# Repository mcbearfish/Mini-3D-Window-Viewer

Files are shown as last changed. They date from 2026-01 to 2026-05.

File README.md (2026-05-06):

# 3D Window Project

## About
This is a developmental project intended to refresh my skills on designing and programming an STM32 microcontroller board. I chose a project scope that I believed would provide difficult circuit and programming challenges. I will document the development process in this README.<br />

If you stumble across this project feel free to use it for educational purposes. If you find errors or have questions about the circuit design or code feel free to reach out. Please cite this repository as a source if you plan to use it.<br />

## Table of Contents
- [Project Description](#project-description)
- [Demo Video](#demo-video)
- [Hardware / Software Used](#hardware--software-used)
- [Circuit Design](#circuit-design)
- [Box Design](#box-design)
- [Code Design](#code-design)
- [Notes on AI Assistance](#notes-on-ai-assistance)
- [Final Result](#final-result)

## Project Description
This project is the 3D Window Viewer.<br />

When placed on a flat surface, the device on startup will create a window into a 3D scene of a hammer (Boiler Up and Hail Purdue!). After startup, tilting and rotating the device updates the view of a 3D hammer while the virtual position remains anchored.<br />

This project uses I2C accelerometer, gyroscope, and magnetometer sensors to estimate device orientation in C. The original goal was IMU-only position tracking, but drift made that impractical, so I redesigned the demo around constrained motion. <br />

I designed my own custom STM32 development board and sensor board using KiCad Schematic and PCB Design Software. <br />

## Demo Video
Everything Is AWESOME (https://www.youtube.com/watch?v=Y7tffPQoLfw "Everything Is AWESOME")

## Hardware / Software Used
- STM32 microcontroller
- Custom STM32 main PCB
- Custom sensor PCB
- Accelerometer, gyroscope, and magnetometer over I2C
- LCD display
- KiCad for schematic and PCB design
- CLion IDE
- C firmware

## Circuit Design
#### STM32 Circuit
<br />
This STM32 chip was chosen for its large number of GPIO pins and processing capabilities.

#### Button
<br />
Simple button circuit to test user inputs.

#### LEDs
<br />
Used for initial testing and debugging.

#### Crystal Oscillator
<br />
Provides a highly stable, accurate, and precise frequency reference.

#### USB-C Connector
<br />
Provides power to the board.

#### Boot Switch
<br />
Reset switch.

#### Mounting Holes
<br />
Grounded pads to use for mounting and probe testing.

#### Pin Connectors
<br />

#### Buck Converter
<br />
Chosen to smooth 5V to 3.3V for STM32 chip and sensors.

#### Accelerometer and Gyroscope
<br />
Chosen to estimate device orientation and motion. IMU-only position tracking was tested, but drift made it impractical for this version.

#### Magnetometer
<br />
Chosen to improve heading estimation and help correct gyro drift over time.

#### Pin Connector
<br />

#### Mounting Holes
<br />

#### Notes
I found Google's Gemini AI tool to be extremely helpful during this design process. Especially with mapping the pinout of the display to STM32. I used a cheap knockoff with no documentation and poor pinout labels. In the future may need to remap pins if display fails to work. See ARSensors project for second Board meant to connect sensors to this main board.<br />

Manufacturing files can be found for each board in this repository.<br />

#### Main PCB
<br />

<br />

<br />

<br />

#### Sensors PCB
<br />

<br />

<br />

<br />

#### Design Process
Designing my first board in almost 4 years was a great experience. In the workspace I have been living in a more software heavy environment. I found this project to be a great refresher of my skills.<br />

I found the initial research phase to be quite enjoyable and straightforward. I easily identified the types of sensors, display, and STM32 chip I thought would be capable for the performance I wanted. Now that I identified the key components it was time to begin creating the schematic.<br />

I quickly realized this was a larger challenge than my senior design project. Although I took a significant part in the circuit design, I realized how beneficial it was having a team of 4 people in multiple disciplines. The components I selected for this project were much more sophisticated than what was chosen for the senior design project. I was honestly a little overwhelmed at the start. I had to take my time and started to break components down. I started with the most important part, the STM32 chip. <br />

For the STM32 I first connected any power related pins and decoupling capacitors. Then I used the STM32CubeMX tool to assign pinouts. I knew between the display and other peripherals I needed a lot of pins, so I started by making sure the chip was capable of supporting them all. Once I verified the chip was capable I began connecting components. The most critical was the USB-C connector, which flashes code onto the chip. The USB-C will also provide power to the whole system. I spent quite a bit of time researching possible power designs. The USB-C provides 5V and I need 3.3V for the STM32 and sensors. I eventually decided on a synchronous buck converter because it would provide an efficient and stable step down from 5V to 3.3V. The display needs 5V, so I decided on a simple low-pass filter because it would provide a clean signal and I have experience with designing those on circuit boards in the past.<br />

Next I added the sensors. I found the datasheets to be extremely helpful. The design process was made much easier by following the typical application circuits that they detailed. Then I added the display, button, and some LEDs. The extra LEDs and button will be useful at the start of programming to make sure the board can properly run code and debug. Lastly I added a connector for debug pins.<br />

Now that I had a schematic to follow I moved onto the PCB layout. This portion was much more difficult than expected. It was at this point I had to take into account physical and cost restrictions. JLCPCB was my choice of board manufacturer. To minimize costs I decided on a 2 layer board, which gave me a lot of physical trace constraints.  Also, since the sensors are a bit costly, I decided to move them to a second circuit board to save on future costs. With these new challenges I had to go back to my schematic and STM32CubeMX. Unfortunately I was not able to place my STM32 pinouts more conveniently to minimize trace crossovers. At this point I decided to go with a more generic pin layout that I can wire with some 2.54mm connectors to minimize my trace lengths and crossovers. In the future I will look at more layered boards or other STM32 chips as potential solutions.<br />

To minimize costs on JLCPCB I tried to identify basic parts in the JLCPCB library. Not all parts selected were in that and drove up the cost (~$3 per part not in the basic library). In the future I will place more emphasis on this to lower my costs.<br />

Major credit to Phil's Lab PCB Design video: https://www.youtube.com/watch?v=aVUqaB0IMh4. This was a great refresher on circuit board design and I highly recommend his channel.<br />

#### Soldering and Assembly
When ordering the board I decided that to save on costs to I would hand solder some of the components. This involved things the STM32 chip, USB-C connector, asynchronous buck converter, buttons, and pins. I felt this was a great skill refresher. I took it slow and steady. I started with easier items like the pins and buttons to get back into the flow of things. The picture below is from right before I went to solder the STM chip.<br />
<br />

I bought a cheap soldering station and found it pretty useful when adding the smaller components. In the picture below you can see a cheaper soldering iron. I found this ok for the larger components but, I decided it was safer to spend the money and get a proper iron for the delicate items like the USB-C and STM32 chip.<br />
<br />

### Box Design
I bought a simple project box and placed the main board inside the box. I left the sensor board on top along with the display to keep them on the same level.


## Code Design
#### Initial Project Scope
The initial goal of the project was to use the IMU sensors to track the 3D coordinates of the device so that it could act as a camera. The camera would then be able to view a 3D object fixed in space from all angles and get closer or farther away.<br />

#### Limitations of IMU Sensors
While prototyping I found that it was not feasible to use the IMU sensors alone for positional tracking. The significant position drift was too much to overcome, even with adjusting bias in the Kalman filter parameters. I also tested the individual sensors to check for noise and bias. Surprisingly, these cheaper sensors performed quite well. The accelerometer did display the most noise. I believe this was due to environmental sensitivities. Testing was performed on my desk and away from any electronics, this however does not guarantee a perfectly still environment. <br />

Since position is calculated by integrating acceleration twice, even with tiny errors, the positional data errors grew massive. The estimated position drifted so quickly that the 3D object would only remain visible for a split second. I determined this was unusable and decided to change scope. <br />

#### Redesign
I decided to pivot the project and try to get the most out of the current setup. I decided to simulate the camera view of the 3D object where moving and tilting the box changes camera view direction realistically, but position is anchored. <br />

#### Code Flow
The main program initializes the board, sensors, sensor fusion, and 3D engine before entering the main loop. In the loop, new sensor data is read and passed into the sensor fusion algorithm. This project uses an Extended Kalman Filter, which fuses gyroscope, accelerometer, and magnetometer data into a stable orientation estimate. That orientation estimate is then used to update the rendered 3D object and draw the pose overlay.<br />
```
main()
|
+-- HAL_Init()
+-- SystemClock_Config()
+-- MX_GPIO_Init()
+-- MX_FMC_Init()
+-- I2C_Bus_Reset()
+-- MX_I2C1_Init()
|
+-- Engine3D_Init()
|   \-- GPU_Init()
|
+-- Sensors_Init()
+-- Sensors_ShowStartupCountdown()
+-- Sensors_Calibrate()
+-- Sensors_ShowInstructionScreen()
+-- Sensors_GetReferenceFrame()
+-- EKF_Init()
+-- EKF_SetReference()
|
\-- while (1)
    +-- Sensors_Read()
    +-- EKF_Predict()
    +-- EKF_Update()
    +-- ComputeSpinCommands()
    +-- IntegrateQuat()
    +-- IsStableForReset()
    |   \-- maybe ResetObjectOrientation()
    +-- QuaternionToEulerDegrees()
    +-- Engine3D_SetCameraPose()
    +-- Engine3D_SetObjectRotation()
    +-- Engine3D_PrepareFrame()
    +-- GPU_Render(Engine3D_DrawScene)
    \-- DrawPoseOverlay()
```

## Notes on AI Assistance
Portions of the firmware were developed with assistance from AI tools, including OpenAI Codex and Google's Gemini. I used these tools to help generate code structure, debug embedded issues and tune parts of the sensor-fusion pipeline. All AI-assisted code was reviewed, tested, and modified by me before being included in the final project. <br />

I found Codex especially useful for working through embedded C issues and code organization. Gemini was useful during early design exploration, especially for brainstorming and pin-mapping support, but I had to review its output carefully because it sometimes suggested larger code changes than intended. <br />

## Final Result
The final device renders a wireframe 3D hammer on the LCD. After startup calibration, tilting or rotating the physical box updates the rendered view in real time. The device uses IMU sensor fusion for orientation estimation while keeping virtual position constrained to avoid IMU drift. <br />

This project was great for refreshing my bare-metal embedded skills. Making a device and writing code that brings it to life is always a joy. The next project should hopefully move faster now that I have regained familiarity with the whole process.

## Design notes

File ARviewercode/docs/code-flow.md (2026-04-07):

# Code Flow

This document summarizes the runtime flow of the AR viewer firmware and the relationship between the main application modules.

## Main Runtime Flow

```text
Power On / main()
|
+-- HAL_Init()
+-- SystemClock_Config()
+-- MX_GPIO_Init()
+-- MX_FMC_Init()
+-- I2C_Bus_Reset()
+-- MX_I2C1_Init()
|
+-- Engine3D_Init()
|   \-- GPU_Init()
|       \-- LCD init + clear screen
|
+-- Sensors_Init()
|   +-- Probe magnetometer
|   |   \-- If found: configure LIS3MDL
|   \-- Probe IMU
|       \-- If found: configure LSM6DS3TR-C
|
+-- Sensors_ShowStartupCountdown()
+-- Sensors_Calibrate()
|   +-- Draw calibration UI
|   +-- Collect still samples
|   +-- Compute gyro bias
|   +-- Compute accel bias/reference
|   \-- Capture mag reference if available
|
+-- Sensors_ShowInstructionScreen()
+-- Sensors_GetReferenceFrame()
+-- EKF_Init()
+-- EKF_SetReference()
|
\-- while (1)
    +-- Sensors_Read()
    |   +-- Read accel
    |   +-- Read gyro
    |   \-- Read mag if available
    |
    +-- Convert gyro mdps to rad/s
    +-- Compute dt from HAL_GetTick
    +-- EKF_Predict()
    +-- Convert accel mg to g
    +-- Magnetometer available?
    |   +-- Yes -> EKF_Update(accel + mag)
    |   \-- No  -> EKF_Update(accel only)
    |
    +-- Read EKF quaternion
    +-- Quaternion valid?
    |   +-- No -> EKF_Init() and continue
    |   \-- Yes
    |
    +-- Compute gravity_body
    +-- ComputeSpinCommands()
    +-- IntegrateQuat(object_q)
    +-- Compute motion magnitude
    +-- IsStableForReset()?
    |   +-- Yes
    |   |   +-- Accumulate still_time_s
    |   |   \-- If still_time_s >= 10 s -> ResetObjectOrientation()
    |   \-- No
    |       \-- Reset still_time_s to 0
    |
    +-- QuaternionToEulerDegrees()
    +-- Engine3D_SetCameraPose()
    +-- Engine3D_SetObjectRotation()
    +-- Engine3D_PrepareFrame()
    |   +-- Rotate vertices
    |   +-- Project points
    |   \-- Build visible line list
    |
    +-- GPU_Render(Engine3D_DrawScene)
    |   +-- Erase previous lines
    |   \-- Draw current lines
    |
    \-- DrawPoseOverlay()
```

## Module Relationships

```text
main.c
|
+-- sensor_helper.c
+-- kalman_filter.c
+-- engine3d.c
|   \-- gpu_driver.c
\-- gpu_driver.c (via sensor/UI drawing paths)
```

## Notes

- `main.c` owns system startup, the main loop, and the high-level application state.
- `sensor_helper.c` handles sensor detection, calibration, reference-frame capture, and live sensor reads.
- `kalman_filter.c` estimates device orientation from gyro, accelerometer, and optional magnetometer data.
- `engine3d.c` converts the current object orientation into projected wireframe line segments.
- `gpu_driver.c` wraps low-level LCD drawing primitives used by both the renderer and the startup/UI screens.

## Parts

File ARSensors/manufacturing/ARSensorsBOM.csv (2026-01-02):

Designator | Comment | Footprint | JLCPCB Part #
C1,C2,C3,C5 | 100n | Capacitor_SMD:C_0402_1005Metric | C1525
C4 | 1u | Capacitor_SMD:C_0402_1005Metric | C52923
R1,R2 | 3k3 | Resistor_SMD:R_0603_1608Metric | C22978
U2 | LIS3MDLTR | footprints1:LGA-12_2X2X1_STM | C478483
U3 | LSM6DSRTR | footprints:LGA-14L_2P5X3X0P83_STM | C784817

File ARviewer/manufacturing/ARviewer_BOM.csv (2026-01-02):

Comment | Designator | Footprint | JLCPCB Part #
10u | C1,C19 | Capacitor_SMD:C_0603_1608Metric | C19702
100n | C2,C3,C4,C5,C6,C8,C10,C11,C15,C17,C20,C22,C23 | Capacitor_SMD:C_0402_1005Metric | C1525
2u2 | C7,C9 | Capacitor_SMD:C_0402_1005Metric | C12530
10n | C12 | Capacitor_SMD:C_0402_1005Metric | C15195
1u | C13,C14 | Capacitor_SMD:C_0402_1005Metric | C52923
14pF | C16,C18 | Capacitor_SMD:C_0402_1005Metric | C458857
10p | C21 | Capacitor_SMD:C_0402_1005Metric | C32949
22u | C24,C25 | Capacitor_SMD:C_0805_2012Metric | C45783
GREEN | D1,D6 | LED_SMD:LED_0603_1608Metric | C2286
ORANGE | D2 | LED_SMD:LED_0603_1608Metric | C2286
BLUE | D3 | LED_SMD:LED_0603_1608Metric | C2286
YELLOW | D4 | LED_SMD:LED_0603_1608Metric | C2286
RED | D5 | LED_SMD:LED_0603_1608Metric | C2286
120R | FB1,FB2 | Inductor_SMD:L_0603_1608Metric | C14709
USB_C_Receptacle_USB2.0_16P | J2 | Connector_USB:USB_C_Receptacle_GCT_USB4105-xx-A_16P_TopMnt_Horizontal | C3020560
3.3u | L1 | Inductor_SMD:L_6.3x6.3_H3 | C206311
100k | R1 | Resistor_SMD:R_0805_2012Metric | C149504
1k | R2 | Resistor_SMD:R_0603_1608Metric | C21190
450 | R3 | Resistor_SMD:R_0402_1005Metric | C159027
1k5 | R4,R5,R6,R8,R9,R15 | Resistor_SMD:R_0603_1608Metric | C22843
10k | R7 | Resistor_SMD:R_0402_1005Metric | C25744
22 | R10 | Resistor_SMD:R_0603_1608Metric | C23345
5k1 | R11,R12 | Resistor_SMD:R_0603_1608Metric | C23186
33k2 | R13 | Resistor_SMD:R_0805_2012Metric | C37252
10k | R14 | Resistor_SMD:R_0805_2012Metric | C17414
SW_Push | SW1 | Button_Switch_THT:SW_PUSH_6mm | C557623
SW_SPDT | SW2 | Button_Switch_SMD:SW_SPDT_PCM12 | C221841
STM32F429VIT6 | U1 | Package_QFP:LQFP-100_14x14mm_P0.5mm | C92002
AP62300TWU-7 | U2 | Package_TO_SOT_SMD:TSOT-23-6 | C1883519
USBLC6-2SC6 | U3 | Package_TO_SOT_SMD:SOT-23-6 | C7519
25MHz | Y1 | Crystal:Crystal_SMD_3225-4Pin_3.2x2.5mm | C9006

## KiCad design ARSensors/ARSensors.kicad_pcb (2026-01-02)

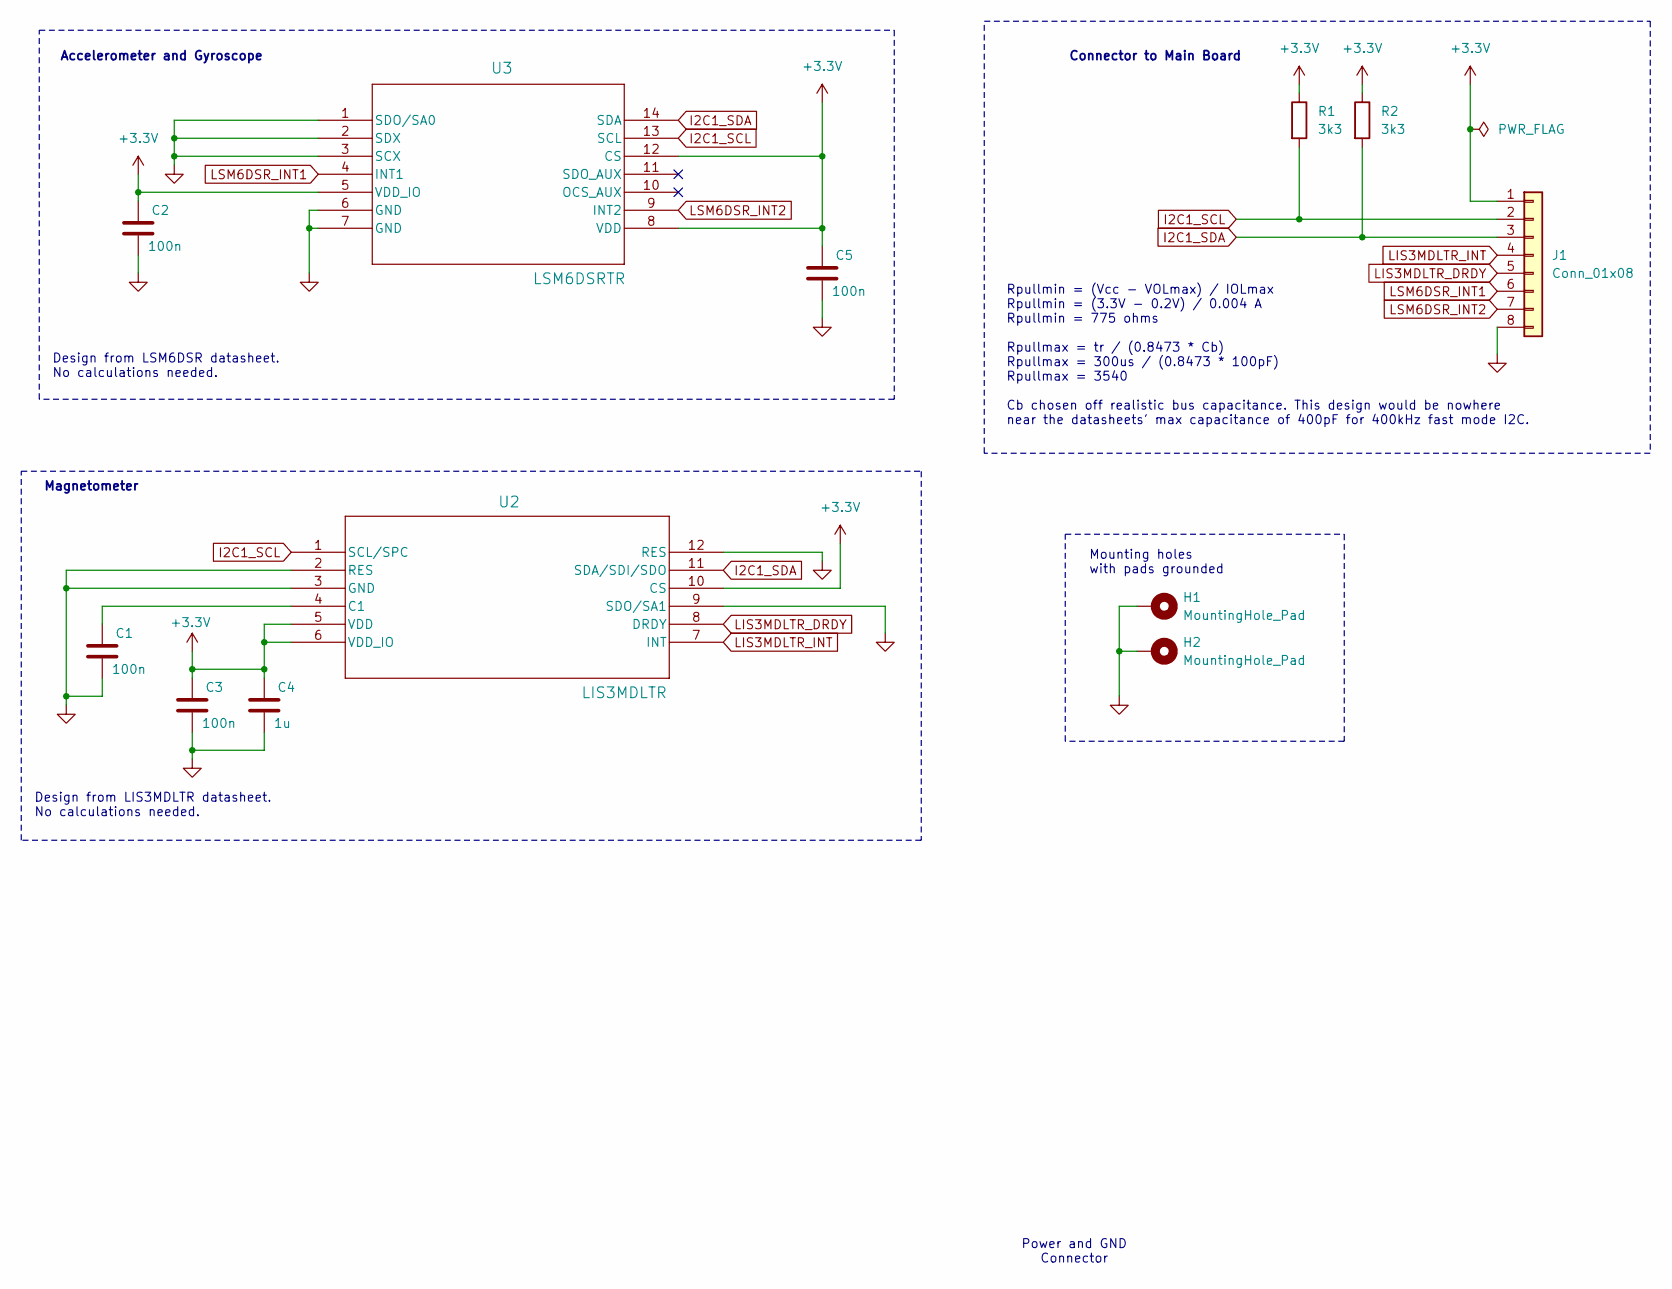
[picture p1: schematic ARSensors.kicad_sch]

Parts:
C1, C2, C3, C5: 100n; C_0402_1005Metric
C4: 1u; C_0402_1005Metric
H1, H2: MountingHole_Pad; MountingHole_4.3mm_M4_Pad_Via
J1: Conn_01x08; PinHeader_1x08_P2.54mm_Vertical
R1, R2: 3k3; R_0603_1608Metric
U2: LIS3MDLTR; LGA-12_2X2X1_STM
U3: LSM6DSRTR; LGA-14L_2P5X3X0P83_STM

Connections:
+3.3V: C2.1, C3.1, C4.1, C5.1, J1.1, R1.1, R2.1, U2.5 (VDD), U2.6 (VDD_IO), U2.10 (CS), U3.5 (VDD_IO), U3.8 (VDD), U3.12 (CS)
GND: C1.2, C2.2, C3.2, C4.2, C5.2, H1.1, H2.1, J1.8, U2.2 (RES), U2.3 (GND), U2.9 (SDO/SA1), U2.12 (RES), U3.1 (SDO/SA0), U3.2 (SDX), U3.3 (SCX), U3.6 (GND), U3.7 (GND)
I2C1_SCL: J1.2, R1.2, U2.1 (SCL/SPC), U3.13 (SCL)
I2C1_SDA: J1.3, R2.2, U2.11 (SDA/SDI/SDO), U3.14 (SDA)
LIS3MDLTR_DRDY: J1.5, U2.8 (DRDY)
LIS3MDLTR_INT: J1.4, U2.7 (INT)
LSM6DSR_INT1: J1.6, U3.4 (INT1)
LSM6DSR_INT2: J1.7, U3.9 (INT2)
unnamed: C1.1, U2.4 (C1)

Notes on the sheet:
Rpullmin = (Vcc - VOLmax) / IOLmax Rpullmin = (3.3V - 0.2V) / 0.004 A Rpullmin = 775 ohms Rpullmax = tr / (0.8473 * Cb) Rpullmax = 300us / (0.8473 * 100pF) Rpullmax = 3540 Cb chosen off realistic bus capacitance. This design would be nowhere near the datasheets' max capacitance of 400pF for 400kHz 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
Design from LIS3MDLTR datasheet. No calculations needed.
Mounting holes with pads grounded
Design from LSM6DSR datasheet. No calculations needed.
Power and GND Connector
Connector to Main Board
Magnetometer
Accelerometer and Gyroscope

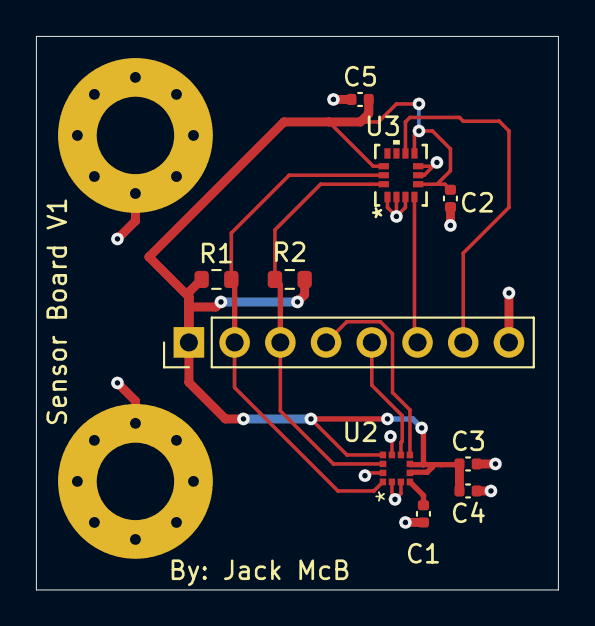
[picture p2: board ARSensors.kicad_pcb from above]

Board: 2 copper layers, 29.0 x 30.8 mm, 12 parts (0 on the bottom side), 9 nets.

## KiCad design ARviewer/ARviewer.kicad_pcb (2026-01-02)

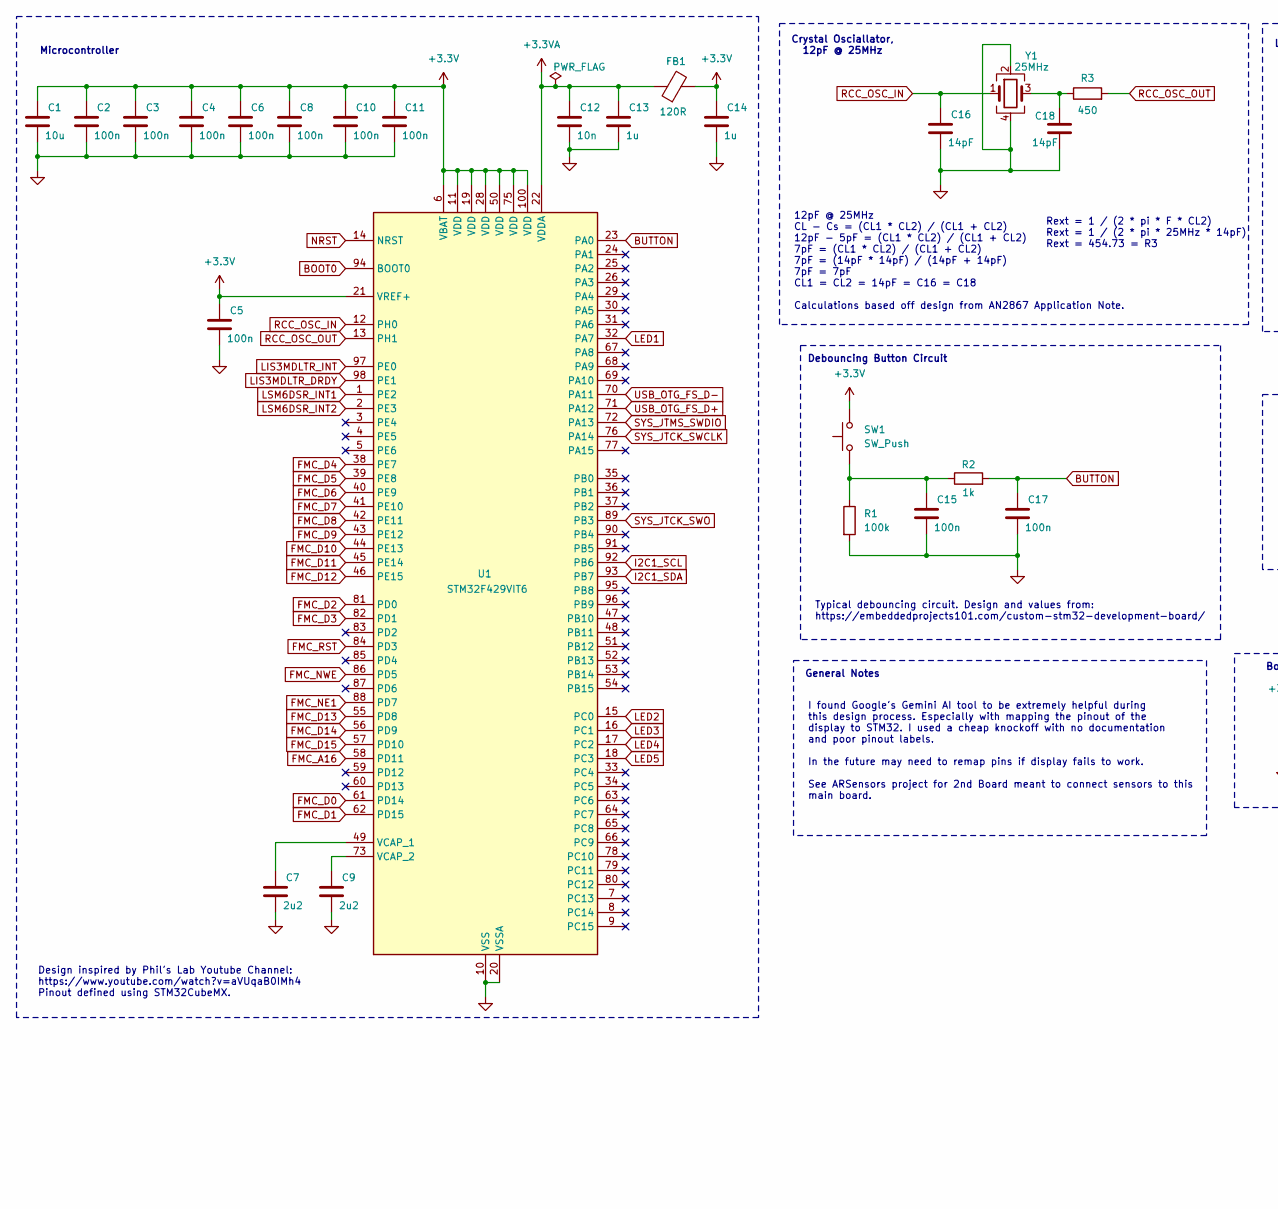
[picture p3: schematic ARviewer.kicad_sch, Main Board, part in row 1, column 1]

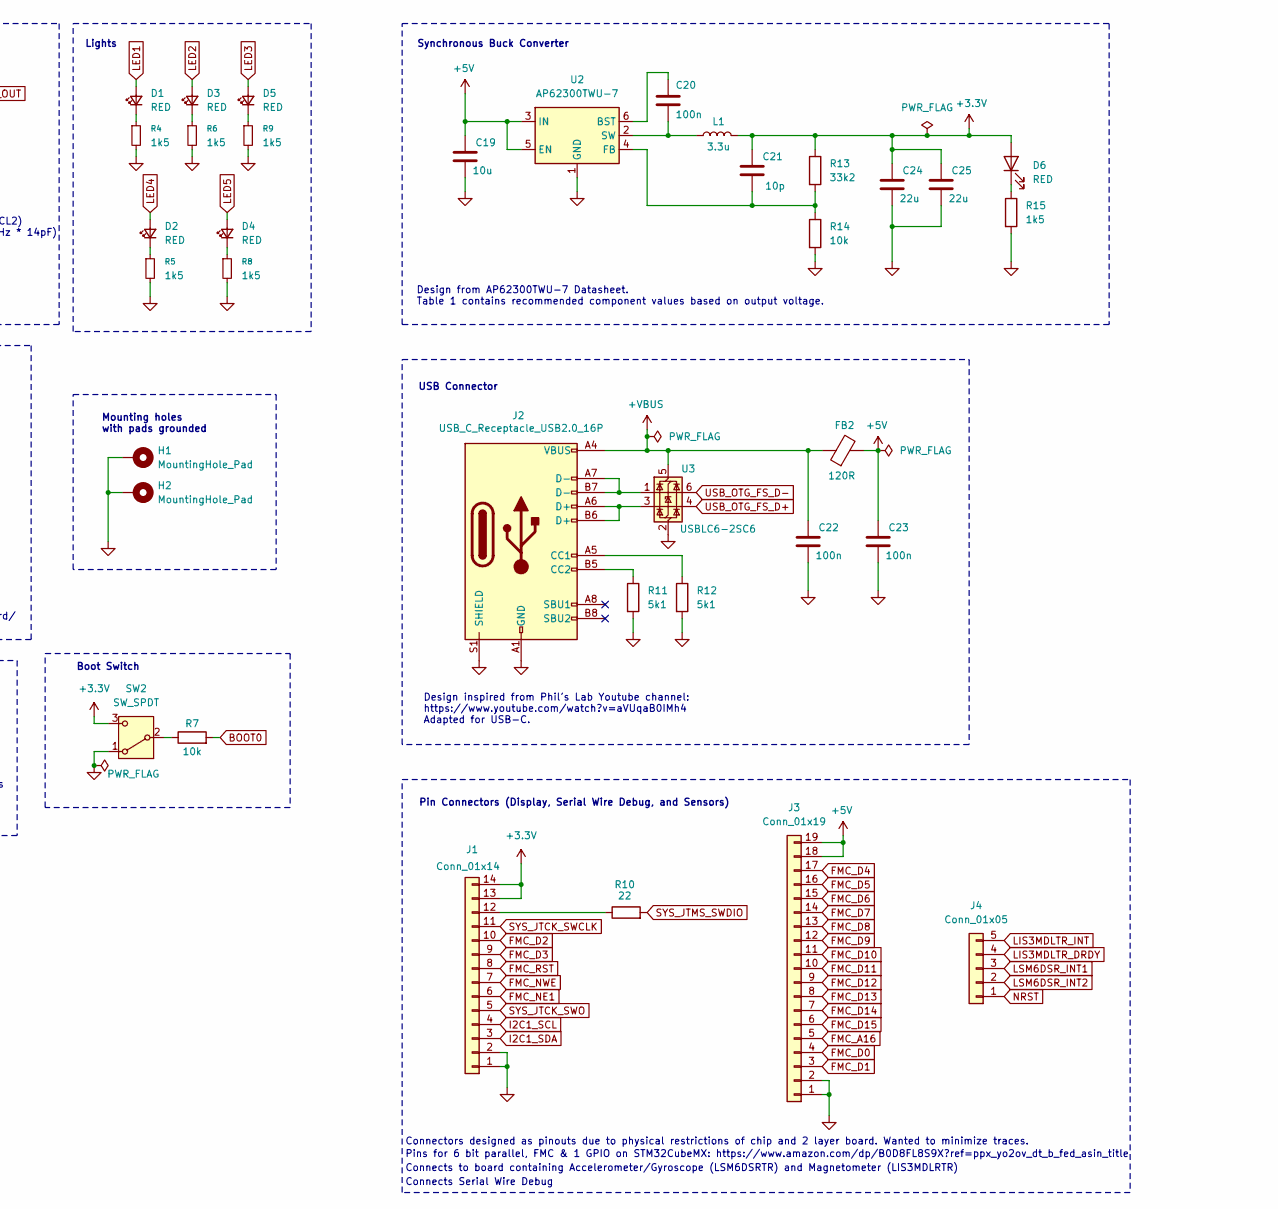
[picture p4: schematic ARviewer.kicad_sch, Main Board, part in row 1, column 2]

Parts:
C1, C19: 10u; C_0603_1608Metric
C2, C3, C4, C5, C6, C8, C10, C11, C15, C17, C20, C22, C23: 100n; C_0402_1005Metric
C7, C9: 2u2; C_0402_1005Metric
C12: 10n; C_0402_1005Metric
C13, C14: 1u; C_0402_1005Metric
C16, C18: 14pF; C_0402_1005Metric
C21: 10p; C_0402_1005Metric
C24, C25: 22u; C_0805_2012Metric
D1, D2, D3, D4, D5, D6: RED; LED_0603_1608Metric
FB1, FB2: 120R; L_0603_1608Metric
H1, H2: MountingHole_Pad; MountingHole_4.3mm_M4_Pad_Via
J1: Conn_01x14; PinHeader_1x14_P2.54mm_Vertical
J2: USB_C_Receptacle_USB2.0_16P; USB_C_Receptacle_GCT_USB4105-xx-A_16P_TopMnt_Horizontal
J3: Conn_01x19; PinHeader_1x19_P2.54mm_Vertical
J4: Conn_01x05; PinHeader_1x05_P2.54mm_Vertical
L1: 3.3u; L_6.3x6.3_H3
R1: 100k; R_0805_2012Metric
R2: 1k; R_0603_1608Metric
R3: 450; R_0402_1005Metric
R4, R5, R6, R8, R9, R15: 1k5; R_0603_1608Metric
R7: 10k; R_0402_1005Metric
R10: 22; R_0603_1608Metric
R11, R12: 5k1; R_0603_1608Metric
R13: 33k2; R_0805_2012Metric
R14: 10k; R_0805_2012Metric
SW1: SW_Push; SW_PUSH_6mm
SW2: SW_SPDT; SW_SPDT_PCM12
U1: STM32F429VIT6; LQFP-100_14x14mm_P0.5mm
U2: AP62300TWU-7; TSOT-23-6
U3: USBLC6-2SC6; SOT-23-6
Y1: 25MHz; Crystal_SMD_3225-4Pin_3.2x2.5mm

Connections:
+3.3V: C1.1, C2.1, C3.1, C4.1, C5.1, C6.1, C8.1, C10.1, C11.1, C14.1, C21.1, C24.1, C25.1, D6.2 (A), FB1.2, J1.13, J1.14, L1.2, R13.1, SW1.2, SW2.3 (C), U1.6 (VBAT), U1.11 (VDD), U1.19 (VDD), U1.21 (VREF+), U1.28 (VDD), U1.50 (VDD), U1.75 (VDD), U1.100 (VDD)
+3.3VA: C12.1, C13.1, FB1.1, U1.22 (VDDA)
+5V: C19.1, C23.1, FB2.2, J3.18, J3.19, U2.3 (IN), U2.5 (EN)
+VBUS: C22.1, FB2.1, J2.A4 (VBUS), J2.A9 (VBUS), J2.B4 (VBUS), J2.B9 (VBUS), U3.5 (VBUS)
BOOT0: R7.2, U1.94 (BOOT0)
BUTTON: C17.1, R2.2, U1.23 (PA0)
FMC_A16: J3.5, U1.58 (PD11)
FMC_D0: J3.4, U1.61 (PD14)
FMC_D1: J3.3, U1.62 (PD15)
FMC_D2: J1.10, U1.81 (PD0)
FMC_D3: J1.9, U1.82 (PD1)
FMC_D4: J3.17, U1.38 (PE7)
FMC_D5: J3.16, U1.39 (PE8)
FMC_D6: J3.15, U1.40 (PE9)
FMC_D7: J3.14, U1.41 (PE10)
FMC_D8: J3.13, U1.42 (PE11)
FMC_D9: J3.12, U1.43 (PE12)
FMC_D10: J3.11, U1.44 (PE13)
FMC_D11: J3.10, U1.45 (PE14)
FMC_D12: J3.9, U1.46 (PE15)
FMC_D13: J3.8, U1.55 (PD8)
FMC_D14: J3.7, U1.56 (PD9)
FMC_D15: J3.6, U1.57 (PD10)
FMC_NE1: J1.6, U1.88 (PD7)
FMC_NWE: J1.7, U1.86 (PD5)
FMC_RST: J1.8, U1.84 (PD3)
GND: C1.2, C2.2, C3.2, C4.2, C5.2, C6.2, C7.2, C8.2, C9.2, C10.2, C11.2, C12.2, C13.2, C14.2, C15.2, C16.2, C17.2, C18.2, C19.2, C22.2, C23.2, C24.2, C25.2, H1.1, H2.1, J1.1, J1.2, J2.A1 (GND), J2.A12 (GND), J2.B1 (GND), J2.B12 (GND), J2.S1 (SHIELD), J3.1, J3.2, R1.2, R4.2, R5.2, R6.2, R8.2, R9.2, R11.2, R12.2, R14.2, R15.2, SW2.1 (A), U1.10 (VSS), U1.20 (VSSA), U1.27 (VSS), U1.74 (VSS), U1.99 (VSS), U2.1 (GND), U3.2 (GND), Y1.2, Y1.4
I2C1_SCL: J1.4, U1.92 (PB6)
I2C1_SDA: J1.3, U1.93 (PB7)
LED1: D1.2 (A), U1.32 (PA7)
LED2: D3.2 (A), U1.15 (PC0)
LED3: D5.2 (A), U1.16 (PC1)
LED4: D2.2 (A), U1.17 (PC2)
LED5: D4.2 (A), U1.18 (PC3)
LIS3MDLTR_DRDY: J4.4, U1.98 (PE1)
LIS3MDLTR_INT: J4.5, U1.97 (PE0)
LSM6DSR_INT1: J4.3, U1.1 (PE2)
LSM6DSR_INT2: J4.2, U1.2 (PE3)
NRST: J4.1, U1.14 (NRST)
unnamed: C15.1, R1.1, R2.1, SW1.1
unnamed: C18.1, R3.1, Y1.3
unnamed: D1.1 (K), R4.1
unnamed: D2.1 (K), R5.1
unnamed: D3.1 (K), R6.1
unnamed: D4.1 (K), R8.1
unnamed: D5.1 (K), R9.1
unnamed: D6.1 (K), R15.1
unnamed: J1.12, R10.1
unnamed: J2.A5 (CC1), R12.1
unnamed: J2.B5 (CC2), R11.1
unnamed: J2.A6 (D+), J2.B6 (D+), U3.3 (I/O2)
unnamed: J2.A7 (D-), J2.B7 (D-), U3.1 (I/O1)
unnamed: R7.1, SW2.2 (B)
unnamed: C7.1, U1.49 (VCAP_1)
unnamed: C9.1, U1.73 (VCAP_2)
unnamed: C20.1, U2.6 (BST)
unnamed: C21.2, R13.2, R14.1, U2.4 (FB)
unnamed: C20.2, L1.1, U2.2 (SW)
RCC_OSC_IN: C16.1, U1.12 (PH0), Y1.1
RCC_OSC_OUT: R3.2, U1.13 (PH1)
SYS_JTCK_SWCLK: J1.11, U1.76 (PA14)
SYS_JTCK_SWO: J1.5, U1.89 (PB3)
SYS_JTMS_SWDIO: R10.2, U1.72 (PA13)
USB_OTG_FS_D+: U1.71 (PA12), U3.4 (I/O2)
USB_OTG_FS_D-: U1.70 (PA11), U3.6 (I/O1)

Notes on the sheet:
Design inspired from Phil's Lab Youtube channel: https://www.youtube.com/watch?v=aVUqaB0IMh4 Adapted for USB-C.
Synchronous Buck Converter
Mounting holes with pads grounded
Typical debouncing circuit. Design and values from: https://embeddedprojects101.com/custom-stm32-development-board/
Design inspired by Phil's Lab Youtube Channel: https://www.youtube.com/watch?v=aVUqaB0IMh4 Pinout defined using STM32CubeMX.
12pF @ 25MHz CL - Cs = (CL1 * CL2) / (CL1 + CL2) 12pF - 5pF = (CL1 * CL2) / (CL1 + CL2) 7pF = (CL1 * CL2) / (CL1 + CL2) 7pF = (14pF * 14pF) / (14pF + 14pF) 7pF = 7pF CL1 = CL2 = 14pF = C16 = C18 Calculations based off design from AN2867 Application Note.
Microcontroller
Design from AP62300TWU-7 Datasheet. Table 1 contains recommended component values based on output voltage.
I found Google's Gemini AI tool to be extremely helpful during this design process. Especially with mapping the pinout of the display to STM32. I used a cheap knockoff with no documentation and poor pinout labels. In the future may need to remap pins if display fails to work. See ARSensors project 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
Boot Switch
Crystal Osciallator, 12pF @ 25MHz
Pin Connectors (Display, Serial Wire Debug, and Sensors)
Pins for 6 bit parallel, FMC & 1 GPIO on STM32CubeMX: https://www.amazon.com/dp/B0D8FL8S9X?ref=ppx_yo2ov_dt_b_fed_asin_title
General Notes
Connectors designed as pinouts due to physical restrictions of chip and 2 layer board. Wanted to minimize traces.
Debouncing Button Circuit
USB Connector
Connects to board containing Accelerometer/Gyroscope (LSM6DSRTR) and Magnetometer (LIS3MDLRTR)
Lights
Connects Serial Wire Debug
Rext = 1 / (2 * pi * F * CL2) Rext = 1 / (2 * pi * 25MHz * 14pF) Rext = 454.73 = R3

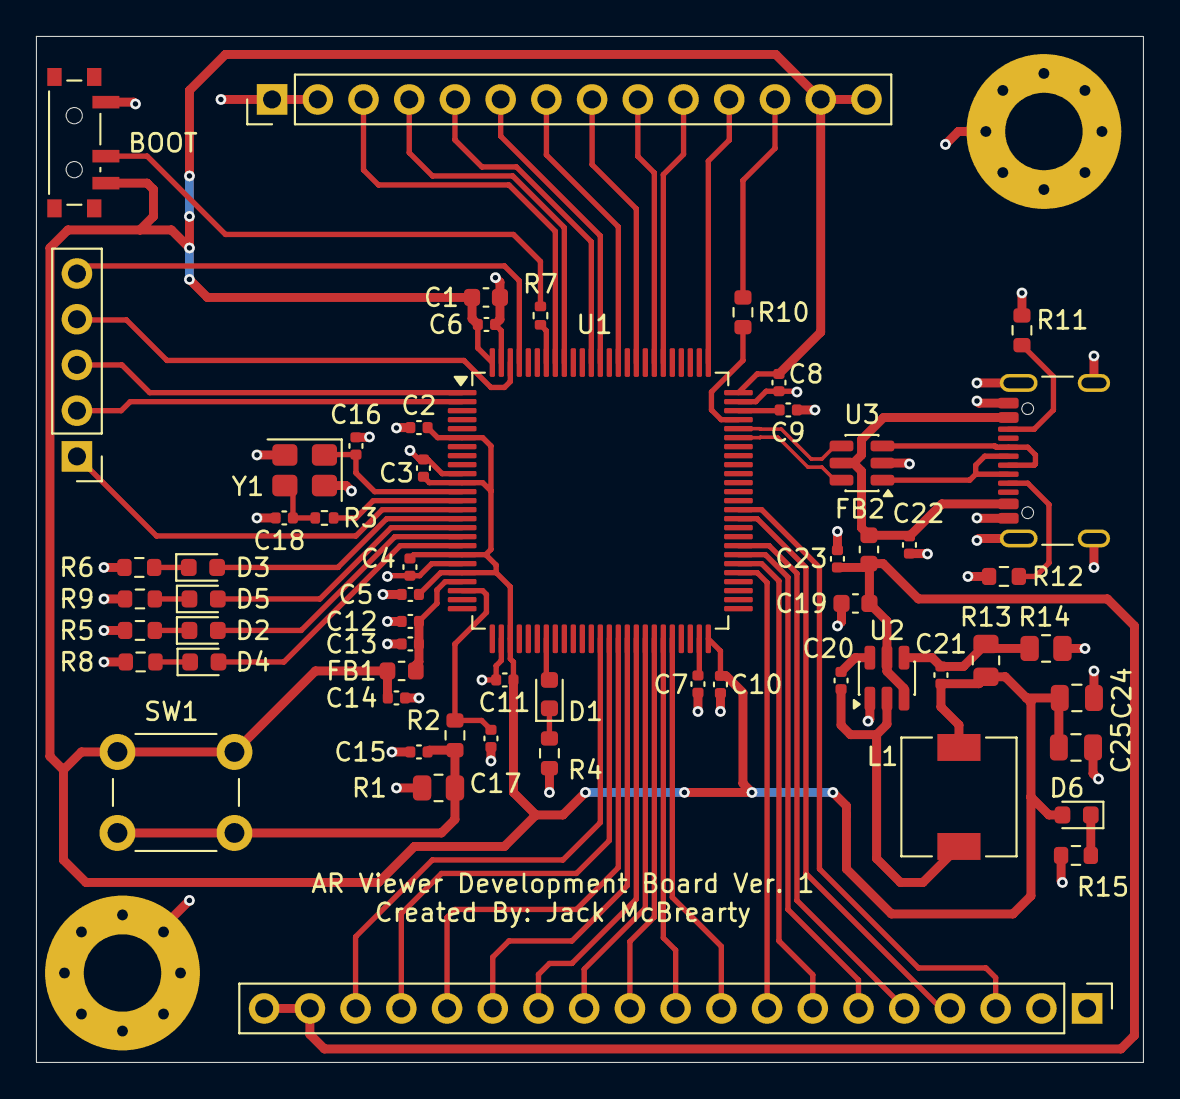
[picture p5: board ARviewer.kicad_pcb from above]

Board: 2 copper layers, 61.5 x 57.0 mm, 61 parts (0 on the bottom side), 65 nets.

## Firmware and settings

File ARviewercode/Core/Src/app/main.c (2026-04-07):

/*----------------------------------------------------------------------------------------*/
/*
 * File:    main.c
 * Purpose: Entry point that initializes the board, runs startup UI and
 *          sensor calibration, and drives the IMU-controlled 3D object demo.
 * Author:  Jack McBrearty
 *
 * Functions contained in this file:
 * - main: Initializes hardware, runs calibration, and executes the main loop.
 * - SystemClock_Config: Configures the STM32 clock tree.
 * - MX_I2C1_Init: Initializes the I2C peripheral.
 * - MX_GPIO_Init: Initializes GPIO used by the board.
 * - MX_FMC_Init: Initializes the external memory controller.
 * - I2C_Bus_Reset: Recovers the sensor bus by manually toggling the I2C lines.
 * - Error_Handler: Traps the firmware after a fatal startup error.
 * - NormalizeQuat: Normalizes a quaternion in place.
 * - IntegrateQuat: Integrates angular velocity into the object's orientation quaternion.
 * - ComputeSpinCommands: Maps physical tilt into object spin commands.
 * - IsStableForReset: Checks if the box has been still long enough to count as stable.
 * - ResetObjectOrientation: Restores the rendered object to default pose.
 * - QuaternionToEulerDegrees: Converts EKF orientation into roll, pitch, and yaw angles.
 * - FormatAngleLine: Formats one overlay angle line without float printf support.
 * - DrawPoseOverlay: Draws the roll, pitch, and yaw overlay in the top-right corner.
 *
 * Notes:
 * - Portions of this codebase were generated and/or optimized using OpenAI's Codex and
 *   Google's Gemini models. I wanted to tinker with how well these two models worked.
 *   I found Codex to be more accurate and followed instructions better. Gemini would tend
 *   to give up easily if instructions were too vague or results did not produce desired
 *   effects. I had to be careful that it would not try to overwrite large chunks. For
 *   example, while trying to fine tune the Kalman filter parameters, Gemini kept trying
 *   to change the code to a complimentary filter.
 * - Overall I found the AI to be an extremely useful tool. I was worried that embedded
 *   development would be difficult but, I was proven wrong. Codex in particular was great
 *   at identifying the limitations of my specific STM32 chip.
 * - I personally verified any additions/changes made by the AI tools.
 */
/*----------------------------------------------------------------------------------------*/


/*----------------------------------------------------------------------------------------*/
// INCLUDES
/*----------------------------------------------------------------------------------------*/
#include "main.h"
#include "engine3d.h"
#include "sensor_helper.h"
#include "kalman_filter.h"
#include <math.h>


/*----------------------------------------------------------------------------------------*/
// GLOBAL VARIABLES
/*----------------------------------------------------------------------------------------*/
// Global HAL handles generated by STM32CubeMX and shared with other modules.
I2C_HandleTypeDef hi2c1;
SRAM_HandleTypeDef hsram1;

// Latest calibrated sensor samples in engineering units.
static float acceleration_mg[3];
static float angular_rate_mdps[3];
static float mag_val[3];

// Reference vectors captured during the startup calibration step.
static float accel_reference_mg[3];
static float mag_reference[3];

// Application state for the orientation filter and rendered object.
EKF_TypeDef ekf;
static float object_q[4] = {1.0f, 0.0f, 0.0f, 0.0f};


/*----------------------------------------------------------------------------------------*/
// CONSTANTS
/*----------------------------------------------------------------------------------------*/
#define TILT_SPIN_GAIN_X      4.5f   // Scale factor that turns X-axis tilt into object spin speed.
#define TILT_SPIN_GAIN_Y      4.5f   // Scale factor that turns Y-axis tilt into object spin speed.
#define TWIST_SPIN_GAIN       1.2f   // Scale factor that turns Z-axis twist into yaw spin speed.
#define TILT_DEADZONE_G       0.08f  // Min tilt magnitude in g before tilt starts rotating the object.
#define TWIST_DEADZONE_RAD_S  0.12f  // Min twist rate in rad/s before twist starts rotating the object.
#define LEVEL_STOP_G          0.04f  // Tilt threshold below which the box is treated as level for stopping motion.
#define LEVEL_STOP_RAD_S      0.08f  // Twist-rate threshold below which the box is treated as not twisting.
#define STILL_RESET_G         0.05f  // Max tilt magnitude allowed while counting toward auto-reset.
#define STILL_RESET_RAD_S     0.09f  // Max rotation magnitude allowed while counting toward auto-reset.
#define STILL_RESET_TIME_S    10.0f  // Time in seconds the box must remain still before the orientation resets.
#define CAMERA_BASE_HEIGHT_IN 3.8f   // Camera height above the object in inches.


/*----------------------------------------------------------------------------------------*/
// FUNCTION DECLARATIONS
/*----------------------------------------------------------------------------------------*/
static void NormalizeQuat(float q[4]);
static void IntegrateQuat(float q[4], float wx, float wy, float wz, float dt);
static void QuaternionToEulerDegrees(float q0, float q1, float q2, float q3, float *roll_deg, float *pitch_deg, float *yaw_deg);
static void FormatAngleLine(char label, float degrees, char out[8]);
static void DrawPoseOverlay(float roll_deg, float pitch_deg, float yaw_deg);
static void ComputeSpinCommands(const float gravity_body[3], float gz, float *spin_x, float *spin_y, float *spin_z);
static uint8_t IsStableForReset(const float gravity_body[3], float motion_mag);
static void ResetObjectOrientation(void);
void SystemClock_Config(void);
static void MX_GPIO_Init(void);
static void MX_I2C1_Init(void);
static void MX_FMC_Init(void);
static void I2C_Bus_Reset(void);


/*----------------------------------------------------------------------------------------*/
/* Function: main
 * Purpose:  Application entry point. Startup performs hardware initialization,
 *           user-visible calibration screens, and EKF setup. The main loop then reads
 *           sensors, updates the orientation estimate, maps tilt into object motion, and
 *           redraws the scene.
 * Returns:  none
 */
/*----------------------------------------------------------------------------------------*/
int main(void)
{
  // Hardware Setup
  HAL_Init();           // Initialize HAL Layer
  SystemClock_Config(); // Initialize clock
  MX_GPIO_Init();       // Enable GPIO pins
  MX_FMC_Init();        // Initialize LCD pins
  I2C_Bus_Reset();      // Reset I2C bus
  MX_I2C1_Init();       // Initialize I2C pins

  // Application Setup
  Engine3D_Init(); // Initialize 3D renderer for UI and object
  Sensors_Init();  // Verify sensors are connected and configure them

  // Startup and Calibration
  Sensors_ShowStartupCountdown();  // Draw startup UI
  Sensors_Calibrate();             // Startup sensors, calculate sensor bias, and draw Calibration UI
  Sensors_ShowInstructionScreen(); // Draw Instruction UI

  // Extended Kalman Filter (EKF) Setup

  // Get the calibrated gravity and magnetometer reference vectors for the EKF.
  Sensors_GetReferenceFrame(accel_reference_mg, mag_reference);

  EKF_Init(&ekf); // Initialize EKF state

  // Load the startup reference frame so the EKF knows what "level" should look like.
  EKF_SetReference(&ekf,
                   // Accelerometer reference X, mg to g.
                   accel_reference_mg[0] / 1000.0f,
                   // Accelerometer reference Y, mg to g.
                   accel_reference_mg[1] / 1000.0f,
                   // Accelerometer reference Z, mg to g.
                   accel_reference_mg[2] / 1000.0f,
                   // Magnetometer reference X.
                   mag_reference[0],
                   // Magnetometer reference Y.
                   mag_reference[1],
                   // Magnetometer reference Z.
                   mag_reference[2]);

  uint32_t last_tick = HAL_GetTick(); // Current tick count, used for delta time
  float still_time_s = 0.0f;          // Time box has remained still, used for auto-reset

  // Main Infinite Loop
  while (1)
  {
    // Read the latest sensor samples.
    Sensors_Read(acceleration_mg, angular_rate_mdps, mag_val);

    // Convert gyroscope units from milli-degrees per sec (mdps) into radians per second for the EKF.
    float gx = (angular_rate_mdps[0] / 1000.0f) * (M_PI / 180.0f); // X axis
    float gy = (angular_rate_mdps[1] / 1000.0f) * (M_PI / 180.0f); // Y axis
    float gz = (angular_rate_mdps[2] / 1000.0f) * (M_PI / 180.0f); // Z axis

    // Calculate delta time from elapsed tick count
    uint32_t tick = HAL_GetTick(); // Current tick count,
    float dt = (tick > last_tick) ? ((float)(tick - last_tick) / 1000.0f) : 0.01f; // delta time
    last_tick = tick;              // Update last tick to current

    if (dt < 0.005f) dt = 0.005f; // Clamp delta time if too small
    if (dt > 0.03f) dt = 0.03f;   // Clamp delta time if too large

    EKF_Predict(&ekf, gx, gy, gz, dt); // Predict next state from gyro values

    // Convert accelerometer units from mg into g for the EKF update step.
    float ax = acceleration_mg[0] / 1000.0f; // X axis
    float ay = acceleration_mg[1] / 1000.0f; // Y axis
    float az = acceleration_mg[2] / 1000.0f; // Z axis

    if (mag_available) {
        // Magnetometer connected, update EKF with all accel and mag values */
        EKF_Update(&ekf, ax, ay, az, mag_val[0], mag_val[1], mag_val[2]);
    } else {
        // Magnetometer disconnected, update EKF with only accel values
        EKF_Update(&ekf, ax, ay, az, 0, 0, 0);
    }

    // Pull the current quaternion estimate out of the EKF state vector.
    float q0 = ekf.x_hat_data[0];
    float q1 = ekf.x_hat_data[1];
    float q2 = ekf.x_hat_data[2];
    float q3 = ekf.x_hat_data[3];

    // Gravity estimate in body coordinates, derived from the quaternion.
    float gravity_body[3];

    // Angular velocity commands that will be applied to the rendered object.
    float spin_x;
    float spin_y;
    float spin_z;

    // Euler-angle versions of the current EKF orientation for the text overlay.
    float roll_deg;
    float pitch_deg;
    float yaw_deg;

    // Combined angular-motion magnitude used by the stillness detector.
    float motion_mag;

    // If the EKF state becomes invalid, reset it and skip this frame to recover cleanly.
    if (isnan(q0)) { EKF_Init(&ekf); continue; }

    // Estimate gravity in body coordinates from the EKF orientation.
    gravity_body[0] = 2.0f * (q1*q3 - q0*q2);        // X axis
    gravity_body[1] = 2.0f * (q2*q3 + q0*q1);        // Y axis
    gravity_body[2] = q0*q0 - q1*q1 - q2*q2 + q3*q3; // Z axis

    // Turn physical tilt into angular velocity commands for the object.
    ComputeSpinCommands(gravity_body, gz, &spin_x, &spin_y, &spin_z);

    // Integrate those spin commands so the rendered object continues moving smoothly.
    IntegrateQuat(object_q, spin_x, spin_y, spin_z, dt);

    // Auto-reset after a long still hold so the demo can recover itself.
    // Treat the total gyro magnitude as a simple measure of how much the box is rotating.
    motion_mag = sqrtf(gx * gx + gy * gy + gz * gz);

    // Check whether the box is still
    if (IsStableForReset(gravity_body, motion_mag)) {
        still_time_s += dt; // Box is still, increment time

        if (still_time_s >= STILL_RESET_TIME_S) {
            ResetObjectOrientation(); // Box has been idle long enough, reset orientation
            still_time_s = 0.0f;      // Reset timer
        }
    } else {
        still_time_s = 0.0f; // Box is moving, reset timer
    }

    // Compute the display angles shown in the row/pitch/yaw overlay.
    QuaternionToEulerDegrees(q0, q1, q2, q3, &roll_deg, &pitch_deg, &yaw_deg);

    // Render the object from a fixed camera position.
    Engine3D_SetCameraPose(0.0f, 0.0f, CAMERA_BASE_HEIGHT_IN);

    // Pass the updated object quaternion to the renderer.
    Engine3D_SetObjectRotation(object_q[0], object_q[1], object_q[2], object_q[3]);

    // Project the 3D wireframe into 2D line segments for this frame.
    Engine3D_PrepareFrame(); //

    // Draw the scene
    GPU_Render(Engine3D_DrawScene);

    // Draw row/pitch/yaw overlay
    DrawPoseOverlay(roll_deg, pitch_deg, yaw_deg);
  }
}

/*----------------------------------------------------------------------------------------*/
/* Function: SystemClock_Config
 * Purpose:  Configure the STM32 system clocks. This is the standard CubeMX-generated clock
 *           tree setup for the board.
 * Returns:  none
 */
/*----------------------------------------------------------------------------------------*/
void SystemClock_Config(void)
{
  RCC_OscInitTypeDef RCC_OscInitStruct = {0};
  RCC_ClkInitTypeDef RCC_ClkInitStruct = {0};
  __HAL_RCC_PWR_CLK_ENABLE();
  __HAL_PWR_VOLTAGESCALING_CONFIG(PWR_REGULATOR_VOLTAGE_SCALE3);
  RCC_OscInitStruct.OscillatorType = RCC_OSCILLATORTYPE_HSI|RCC_OSCILLATORTYPE_HSE;
  RCC_OscInitStruct.HSEState = RCC_HSE_ON;
  RCC_OscInitStruct.HSIState = RCC_HSI_ON;
  RCC_OscInitStruct.HSICalibrationValue = RCC_HSICALIBRATION_DEFAULT;
  RCC_OscInitStruct.PLL.PLLState = RCC_PLL_ON;
  RCC_OscInitStruct.PLL.PLLSource = RCC_PLLSOURCE_HSE;
  RCC_OscInitStruct.PLL.PLLM = 15;
  RCC_OscInitStruct.PLL.PLLN = 144;
  RCC_OscInitStruct.PLL.PLLP = RCC_PLLP_DIV2;
  RCC_OscInitStruct.PLL.PLLQ = 5;
  if (HAL_RCC_OscConfig(&RCC_OscInitStruct) != HAL_OK) Error_Handler();
  RCC_ClkInitStruct.ClockType = RCC_CLOCKTYPE_HCLK|RCC_CLOCKTYPE_SYSCLK|RCC_CLOCKTYPE_PCLK1|RCC_CLOCKTYPE_PCLK2;
  RCC_ClkInitStruct.SYSCLKSource = RCC_SYSCLKSOURCE_HSI;
  RCC_ClkInitStruct.AHBCLKDivider = RCC_SYSCLK_DIV1;
  RCC_ClkInitStruct.APB1CLKDivider = RCC_HCLK_DIV1;
  RCC_ClkInitStruct.APB2CLKDivider = RCC_HCLK_DIV1;
  if (HAL_RCC_ClockConfig(&RCC_ClkInitStruct, FLASH_LATENCY_0) != HAL_OK) Error_Handler();
}

/*----------------------------------------------------------------------------------------*/
/* Function: MX_I2C1_Init
 * Purpose:  Initialize the I2C peripheral used by the IMU devices.
 * Returns:  none
 */
/*----------------------------------------------------------------------------------------*/
void MX_I2C1_Init(void)
{
  hi2c1.Instance = I2C1;
  hi2c1.Init.ClockSpeed = 100000;
  hi2c1.Init.DutyCycle = I2C_DUTYCYCLE_2;
  hi2c1.Init.OwnAddress1 = 0;
  hi2c1.Init.AddressingMode = I2C_ADDRESSINGMODE_7BIT;
  hi2c1.Init.DualAddressMode = I2C_DUALADDRESS_DISABLE;
  hi2c1.Init.OwnAddress2 = 0;
  hi2c1.Init.GeneralCallMode = I2C_GENERALCALL_DISABLE;
  hi2c1.Init.NoStretchMode = I2C_NOSTRETCH_DISABLE;
  if (HAL_I2C_Init(&hi2c1) != HAL_OK) Error_Handler();
}

/*----------------------------------------------------------------------------------------*/
/* Function: MX_GPIO_Init
 * Purpose:  Enable and initialize the GPIO blocks used by the project. Most of the
 *           detailed pin muxing is board-specific and generated by STM32Cube.
 * Returns:  none
 */
/*----------------------------------------------------------------------------------------*/
void MX_GPIO_Init(void)
{
  __HAL_RCC_GPIOE_CLK_ENABLE();
  __HAL_RCC_GPIOH_CLK_ENABLE();
  __HAL_RCC_GPIOC_CLK_ENABLE();
  __HAL_RCC_GPIOA_CLK_ENABLE();
  __HAL_RCC_GPIOD_CLK_ENABLE();
  __HAL_RCC_GPIOB_CLK_ENABLE();
  HAL_GPIO_WritePin(GPIOC, GPIO_PIN_0|GPIO_PIN_1|GPIO_PIN_2|GPIO_PIN_3, GPIO_PIN_RESET);
  HAL_GPIO_WritePin(GPIOA, GPIO_PIN_7, GPIO_PIN_RESET);
  HAL_GPIO_WritePin(GPIOD, GPIO_PIN_3, GPIO_PIN_RESET);
}

/*----------------------------------------------------------------------------------------*/
/* Function: MX_FMC_Init
 * Purpose:  Initialize the external memory controller for the LCD interface.
 * Returns:  none
 */
/*----------------------------------------------------------------------------------------*/
static void MX_FMC_Init(void)
{
  FMC_NORSRAM_TimingTypeDef Timing = {0};
  hsram1.Instance = FMC_NORSRAM_DEVICE;
  hsram1.Extended = FMC_NORSRAM_EXTENDED_DEVICE;
  hsram1.Init.NSBank = FMC_NORSRAM_BANK1;
  hsram1.Init.DataAddressMux = FMC_DATA_ADDRESS_MUX_DISABLE;
  hsram1.Init.MemoryType = FMC_MEMORY_TYPE_SRAM;
  hsram1.Init.MemoryDataWidth = FMC_NORSRAM_MEM_BUS_WIDTH_16;
  hsram1.Init.BurstAccessMode = FMC_BURST_ACCESS_MODE_DISABLE;
  hsram1.Init.WaitSignalPolarity = FMC_WAIT_SIGNAL_POLARITY_LOW;
  hsram1.Init.WrapMode = FMC_WRAP_MODE_DISABLE;
  hsram1.Init.WaitSignalActive = FMC_WAIT_TIMING_BEFORE_WS;
  hsram1.Init.WriteOperation = FMC_WRITE_OPERATION_ENABLE;
  hsram1.Init.WaitSignal = FMC_WAIT_SIGNAL_DISABLE;
  hsram1.Init.ExtendedMode = FMC_EXTENDED_MODE_DISABLE;
  hsram1.Init.AsynchronousWait = FMC_ASYNCHRONOUS_WAIT_DISABLE;
  hsram1.Init.WriteBurst = FMC_WRITE_BURST_DISABLE;
  hsram1.Init.ContinuousClock = FMC_CONTINUOUS_CLOCK_SYNC_ONLY;
  hsram1.Init.PageSize = FMC_PAGE_SIZE_NONE;
  Timing.AddressSetupTime = 5;
  Timing.AddressHoldTime = 0;
  Timing.DataSetupTime = 9;
  Timing.BusTurnAroundDuration = 0;
  Timing.CLKDivision = 16;
  Timing.DataLatency = 17;
  Timing.AccessMode = FMC_ACCESS_MODE_A;
  if (HAL_SRAM_Init(&hsram1, &Timing, NULL) != HAL_OK) Error_Handler();
}

/*----------------------------------------------------------------------------------------*/
/* Function: I2C_Bus_Reset
 * Purpose: Manually toggle the I2C bus lines to recover from a stuck peripheral. This is
 *          useful on power-up when one of the sensors holds SDA/SCL in an unexpected state.
 * Returns: none
 */
/*----------------------------------------------------------------------------------------*/
void I2C_Bus_Reset(void)
{
  GPIO_InitTypeDef GPIO_InitStruct = {0};
  __HAL_RCC_GPIOB_CLK_ENABLE();
  GPIO_InitStruct.Pin = GPIO_PIN_6 | GPIO_PIN_7;
  GPIO_InitStruct.Mode = GPIO_MODE_OUTPUT_OD;
  GPIO_InitStruct.Pull = GPIO_NOPULL;
  GPIO_InitStruct.Speed = GPIO_SPEED_FREQ_VERY_HIGH;
  HAL_GPIO_Init(GPIOB, &GPIO_InitStruct);
  HAL_GPIO_WritePin(GPIOB, GPIO_PIN_7, GPIO_PIN_SET);
  HAL_Delay(5);
  for(int i = 0; i < 9; i++)
  {
    HAL_GPIO_WritePin(GPIOB, GPIO_PIN_6, GPIO_PIN_RESET);
    HAL_Delay(5);
    HAL_GPIO_WritePin(GPIOB, GPIO_PIN_6, GPIO_PIN_SET);
    HAL_Delay(5);
  }
  HAL_GPIO_WritePin(GPIOB, GPIO_PIN_7, GPIO_PIN_RESET);
  HAL_Delay(5);
  HAL_GPIO_WritePin(GPIOB, GPIO_PIN_6, GPIO_PIN_SET);
  HAL_Delay(5);
  HAL_GPIO_WritePin(GPIOB, GPIO_PIN_7, GPIO_PIN_SET);
  HAL_Delay(5);
  HAL_GPIO_DeInit(GPIOB, GPIO_PIN_6 | GPIO_PIN_7);
}

/*----------------------------------------------------------------------------------------*/
/* Function: Error_Handler
 * Purpose:  Trap the firmware in an infinite loop after a fatal initialization error.
 * Returns:  none
 */
/*----------------------------------------------------------------------------------------*/
void Error_Handler(void)
{
  __disable_irq();
  while (1) {}
}

/*----------------------------------------------------------------------------------------*/
/* Function: NormalizeQuat
 * Purpose:  Normalize the quaternion after updates so the rotation state remains a valid
 *           unit quaternion and does not drift from accumulated numerical error.
 * Returns:  none
 */
/*----------------------------------------------------------------------------------------*/
static void NormalizeQuat(float q[4])
{
  // Compute the quaternion magnitude so it can be scaled back to unit length.
  float norm = sqrtf(q[0]*q[0] + q[1]*q[1] + q[2]*q[2] + q[3]*q[3]);

  // If the norm is large enough to be safe, divide each component by that norm.
  if (norm > 1e-6f) {
    // Normalize the scalar, X, Y, and Z components.
    q[0] /= norm;
    q[1] /= norm;
    q[2] /= norm;
    q[3] /= norm;
  } else {
    // If the quaternion collapses numerically, fall back to the identity rotation.
    q[0] = 1.0f;
    q[1] = 0.0f;
    q[2] = 0.0f;
    q[3] = 0.0f;
  }
}

/*----------------------------------------------------------------------------------------*/
/* Function: IntegrateQuat
 * Purpose:  Apply angular velocity over the current time step to update the object's
 *           orientation quaternion, which controls how the hammer is rendered.
 * Returns:  none
 */
/*----------------------------------------------------------------------------------------*/
static void IntegrateQuat(float q[4], float wx, float wy, float wz, float dt)
{
  float q_dot[4];  // Temporary quaternion derivative used for one integration step.

  q_dot[0] = 0.5f * (-q[1] * wx - q[2] * wy - q[3] * wz); // Change in scalar component.
  q_dot[1] = 0.5f * ( q[0] * wx + q[2] * wz - q[3] * wy); // Change in X vector component.
  q_dot[2] = 0.5f * ( q[0] * wy - q[1] * wz + q[3] * wx); // Change in Y vector component.
  q_dot[3] = 0.5f * ( q[0] * wz + q[1] * wy - q[2] * wx); // Change in Z vector component.

  q[0] += q_dot[0] * dt; // Advance the scalar term by the current frame time.
  q[1] += q_dot[1] * dt; // Advance the X component by the current frame time.
  q[2] += q_dot[2] * dt; // Advance the Y component by the current frame time.
  q[3] += q_dot[3] * dt; // Advance the Z component by the current frame time.
  NormalizeQuat(q);      // Re-normalize so the quaternion stays a valid unit rotation.
}
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

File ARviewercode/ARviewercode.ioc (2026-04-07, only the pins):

Mcu.UserName=STM32F429VITx
PA0/WKUP.Signal=GPIO_Input
PA11.Signal=USB_OTG_FS_DM
PA12.Signal=USB_OTG_FS_DP
PA13.Signal=SYS_JTMS-SWDIO
PA14.Signal=SYS_JTCK-SWCLK
PA7.Signal=GPIO_Output
PB3.Signal=SYS_JTDO-SWO
PB6.Signal=I2C1_SCL
PB7.Signal=I2C1_SDA
PC0.Signal=GPIO_Output
PC1.Signal=GPIO_Output
PC2.Signal=GPIO_Output
PC3.Signal=GPIO_Output
PD0.Signal=FMC_D2
PD1.Signal=FMC_D3
PD10.Signal=FMC_D15
PD11.Signal=FMC_A16
PD14.Signal=FMC_D0
PD15.Signal=FMC_D1
PD3.GPIO_Label=FMC_RST
PD3.Signal=GPIO_Output
PD4.Signal=FMC_NOE
PD5.Signal=FMC_NWE
PD7.Signal=FMC_NE1
PD8.Signal=FMC_D13
PD9.Signal=FMC_D14
PE0.GPIO_Label=LIS3MDLTR_INT
PE0.Signal=GPXTI0
PE1.GPIO_Label=LIS3MDLTR_DRDY
PE1.Signal=GPXTI1
PE10.Signal=FMC_D7
PE11.Signal=FMC_D8
PE12.Signal=FMC_D9
PE13.Signal=FMC_D10
PE14.Signal=FMC_D11
PE15.Signal=FMC_D12
PE2.GPIO_Label=LSM6DR_INT1
PE2.Signal=GPXTI2
PE3.GPIO_Label=LSM6DR_INT2
PE3.Signal=GPXTI3
PE7.Signal=FMC_D4
PE8.Signal=FMC_D5
PE9.Signal=FMC_D6
PH0/OSC_IN.Signal=RCC_OSC_IN
PH1/OSC_OUT.Signal=RCC_OSC_OUT

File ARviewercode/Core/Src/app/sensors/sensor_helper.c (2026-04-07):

/*----------------------------------------------------------------------------------------*/
/*
 * File:    sensor_helper.c
 * Purpose: Sensor bring-up, startup calibration, startup UI screens, and
 *          bias-corrected sensor readout for the IMU and magnetometer stack.
 *
 * Functions contained in this file:
 * - DrawCenteredTextLine: Draws a centered status line using the bitmap font.
 * - DrawCountdownScreen: Draws the green keep-still countdown screen.
 * - DrawCalibrationScreen: Draws the red calibration screen.
 * - DrawCalibrationProgress: Updates the calibration progress bar.
 * - DrawReadyScreen: Draws the short READY confirmation screen.
 * - DrawInstructionScreen: Draws the interaction instructions screen.
 * - platform_write: Writes bytes to the IMU through the ST driver callback.
 * - platform_read: Reads bytes from the IMU through the ST driver callback.
 * - SENSOR_IO_Init: Board-support initialization shim for sensor drivers.
 * - SENSOR_IO_DeInit: Board-support deinitialization shim for sensor drivers.
 * - SENSOR_IO_Write: Writes one sensor register through the BSP wrapper.
 * - SENSOR_IO_Read: Reads one sensor register through the BSP wrapper.
 * - SENSOR_IO_ReadMultiple: Reads multiple sensor bytes through the BSP wrapper.
 * - SENSOR_IO_WriteMultiple: Writes multiple sensor bytes through the BSP wrapper.
 * - Sensors_Init: Probes and configures the IMU and magnetometer.
 * - Sensors_ShowStartupCountdown: Shows the startup countdown screen.
 * - Sensors_Calibrate: Collects still samples and computes startup bias terms.
 * - Sensors_ShowInstructionScreen: Shows the short instruction screen.
 * - Sensors_Read: Returns the latest calibrated sensor values.
 * - Sensors_GetReferenceFrame: Returns calibration reference vectors for the EKF.
 */
/*----------------------------------------------------------------------------------------*/

/*----------------------------------------------------------------------------------------*/
// INCLUDES
/*----------------------------------------------------------------------------------------*/
#include "sensor_helper.h"
#include "gpu_driver.h"
#include <string.h>


/*----------------------------------------------------------------------------------------*/
// GLOBAL VARIABLES
/*----------------------------------------------------------------------------------------*/
extern I2C_HandleTypeDef hi2c1;

/* Public availability flags checked by the main loop and EKF setup. */
uint8_t mag_available = 0;
uint8_t accel_available = 0;

/* Low-level IMU device context used by the ST sensor driver. */
static uint8_t lsm_addr = LSM6DS3TR_C_I2C_ADD_L & 0xFE;
static stmdev_ctx_t dev_ctx;
static uint8_t whoamI, rst;

/* Calibration values derived from the startup stillness capture. */
static float gyro_bias[3] = {0.0f, 0.0f, 0.0f};
static float accel_bias[3] = {0.0f, 0.0f, 0.0f};
static float mag_offset[3] = {0.0f, 0.0f, 0.0f};
static float accel_reference_mg[3] = {0.0f, 0.0f, 1000.0f};
static float mag_reference[3] = {1.0f, 0.0f, 0.0f};


/*----------------------------------------------------------------------------------------*/
/* Function: DrawCenteredTextLine
 * Purpose:  Draw a single centered text line using the tiny built-in bitmap font.
 * Returns:  none
 */
/*----------------------------------------------------------------------------------------*/
static void DrawCenteredTextLine(int y, const char *text, uint16_t color, int scale) {
  int width = (int)strlen(text) * 6 * scale;  // Estimate text width from glyph width and scale.
  int x = (SCR_WIDTH - width) / 2;            // Compute centered X position.
  if (x < 0) {
    x = 0; // Clamp to the left edge if the text is wider than the screen.
  }
  GPU_DrawText(x, y, text, color, scale); // Draw the centered text line.
}


/*----------------------------------------------------------------------------------------*/
/* Function: DrawCountdownScreen
 * Purpose:  Draw the green startup hold-still countdown.
 * Returns:  none
 */
/*----------------------------------------------------------------------------------------*/
static void DrawCountdownScreen(int value) {
  char countdown_text[2] = {'0', '\0'}; // One-digit countdown plus string terminator.

  countdown_text[0] = (char)('0' + value); // Convert the numeric countdown value to ASCII.

  GPU_FillScreen(COLOR_GREEN); // Clear the screen with the startup background color.
  DrawCenteredTextLine(60, "KEEP STILL", COLOR_BLACK, 5);      // Top instruction line.
  DrawCenteredTextLine(120, "FOR 5 SECONDS", COLOR_BLACK, 4);  // Secondary instruction line.
  DrawCenteredTextLine(210, countdown_text, COLOR_BLACK, 10);      // Large numeric countdown.
}


/*----------------------------------------------------------------------------------------*/
/* Function: DrawCalibrationScreen
 * Purpose:  Draw the red calibration screen before and during averaging.
 * Returns:  none
 */
/*----------------------------------------------------------------------------------------*/
static void DrawCalibrationScreen(void) {
  GPU_FillScreen(COLOR_RED); // Fill screen with calibration background color.
  DrawCenteredTextLine(110, "CALIBRATING", COLOR_WHITE, 5); // Main calibration label.
  DrawCenteredTextLine(180, "KEEP STILL", COLOR_WHITE, 4);  // Reminder to the user.
}


/*----------------------------------------------------------------------------------------*/
/* Function: DrawCalibrationProgress
 * Purpose:  Draw the calibration progress bar. The outer white rectangle stays fixed while
 *           the green fill grows as more calibration samples are collected.
 * Returns:  none
 */
/*----------------------------------------------------------------------------------------*/
static void DrawCalibrationProgress(int progress_width) {
  GPU_FillRect(88, 245, 304, 24, COLOR_WHITE); // Draw the white border/background of the bar.
  GPU_FillRect(92, 249, 296, 16, COLOR_BLACK); // Clear the inner bar area before drawing progress.
  if (progress_width > 0) {
    // Fill the completed portion of the progress bar.
    GPU_FillRect(92, 249, progress_width, 16, COLOR_GREEN);
  }
}


/*----------------------------------------------------------------------------------------*/
/* Function: DrawReadyScreen
 * Purpose:  Draw the brief READY confirmation after calibration completes.
 * Returns:  none
 */
/*----------------------------------------------------------------------------------------*/
static void DrawReadyScreen(void) {
  GPU_FillScreen(COLOR_GREEN); // Show a green success background.
  DrawCenteredTextLine(120, "READY", COLOR_BLACK, 6); // Draw the READY message.
}
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

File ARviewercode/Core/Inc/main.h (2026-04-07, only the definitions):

#define LSM6DR_INT1_Pin GPIO_PIN_2
#define LSM6DR_INT1_GPIO_Port GPIOE
#define LSM6DR_INT2_Pin GPIO_PIN_3
#define LSM6DR_INT2_GPIO_Port GPIOE
#define FMC_RST_Pin GPIO_PIN_3
#define FMC_RST_GPIO_Port GPIOD
#define LIS3MDLTR_INT_Pin GPIO_PIN_0
#define LIS3MDLTR_INT_GPIO_Port GPIOE
#define LIS3MDLTR_DRDY_Pin GPIO_PIN_1
#define LIS3MDLTR_DRDY_GPIO_Port GPIOE

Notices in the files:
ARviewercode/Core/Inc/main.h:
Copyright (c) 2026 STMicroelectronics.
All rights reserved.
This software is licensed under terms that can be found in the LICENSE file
